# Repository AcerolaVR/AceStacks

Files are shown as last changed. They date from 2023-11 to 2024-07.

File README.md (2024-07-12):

# AceStacks
A compact, easy-to-assemble SlimeVR tracker design using all the standard recommended DIY tracker parts, and the commonly available 16340 battery.
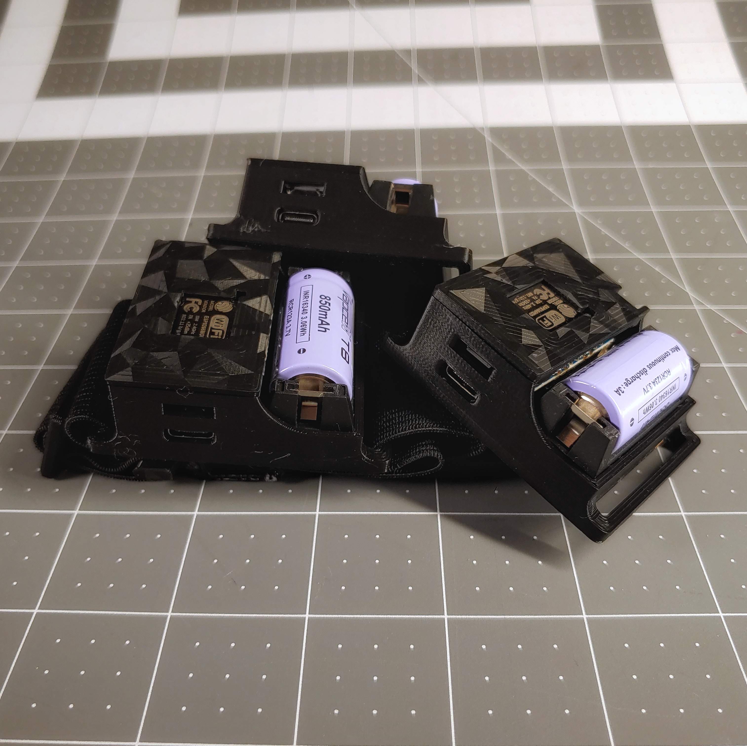
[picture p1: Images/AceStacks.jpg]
Screenshot of AceStacks V1 Trackers

# Overview
AceStacks is a compact, easy-to-assemble SlimeVR tracker design using all the standard recommended DIY tracker parts, and the commonly available 16340 battery. Here are some of the standout features of the AceStacks trackers.

- The use of the included pin sockets of the D1 Mini allows the MCU to be mounted over the charging board, resulting in a compact PCB footprint.
- The design of the board reduces the number of pin headers that need to be trimmed, one of the more annoying parts of DIY trackers with PCBs.
- 16340 cells are easier to obtain (in the United States, not sure about the rest of the world), relatively cheap, more durable compared to li-po pouch cells, and hot swappable if you need more battery life

This arrangement allows for a compact full body tracker with ~8 hours of battery life, battery sense, AUX tracker support, and a hot swappable battery.

# Parts
Refer to the Official SlimeVR Component Guide for more info https://docs.slimevr.dev/diy/components-guide.html

## Required Parts
- Microcontroller: Wemos D1 Mini // https://www.aliexpress.com/w/wholesale-D1-mini.html
- IMU: BMI160 // https://www.aliexpress.com/w/wholesale-BMI160.html
- Charging Board: TP4056 // https://www.aliexpress.us/item/2251832463465716.html
- Batteries: 16450 Li-ion Batteries // https://illumn.com/16340-vapcell-inr16340-t8-850mah-3a-high-discharge-button-top.html or https://liionwholesale.com/products/vapcell-t8-16340-rcr123a-3a-button-top-850mah-battery-genuine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
- CR123/16340 Battery Holders // https://www.aliexpress.com/w/wholesale-cr123-holder.html
- Power Switches: 12d19 Horizontal Switches // https://www.aliexpress.com/w/wholesale-12D19.html
- Straps: 1.5in or 38mm Straps // https://www.aliexpress.us/item/3256801722425879.html or 
https://www.aliexpress.us/item/3256802873749389.html

## Optional Parts
For Battery Percentage
- Resistors: 0805 SMD 180K Resistor // https://www.aliexpress.us/item/3256801607747550.html

For Charge Protection (a Jumper Pad is Provided if You Don't Use These"
- B5817W SOD-123 SMD Schottky Diodes // https://www.lcsc.com/product-detail/Schottky-Barrier-Diodes-SBD_JSMSEMI-B5817W_C917035.html

For Removable Extensions
- JST ZH1.5 4P Vertical Connector // https://www.aliexpress.us/item/3256802928739446.html
- JST ZH1.5 4P Wire // https://www.aliexpress.us/item/3256802896025388.html
Make sure you get the right pitch (ZH, p1.5) and pin count (4p)
The extension wires can be soldered directly to the same holes the JST connector is soldered to, but using a JST allows removal of the extension

# Setup
## AceStacks Specific Setup
Information related to the ports, battery, and layout for the AceStacks Tracker
https://www.youtube.com/watch?v=jQLkWUqJBMk

- There are two ports, the bottom USB C port is for charging the battery, though the battery can be removed and charged in an appropriate Lithium Ion battery charger.
- The top Micro-USB port is for data. You’ll use the data port during initial setup to configure the wi-fi and to debug the trackers if necessary.
- SlimeVR trackers are programmed with a set orientation. As programmed, AceStacks should be worn on the body such that the USB ports are facing the ceiling. This only matters for manual mounting.

### Data Port Quirks
The USB cable may not fully seat in the data port, preventing a proper data connection with the tracker. If you’re having trouble connecting, try the following
- Hold and firmly press the cable into the tracker to form a proper connection
- Use a USB cable with, or trim back the rubber sheath on a cable to allow you to insert the USB cable further into the port
- If neither of the above work, you may need to partially disassemble the tracker, remove the microcontroller, and connect directly to the usb port

### Safety, Charging and Battery Information
If replacing the battery, such as to place fresh ones in or if one accidentally fell out, make sure to place the battery polarity correctly.
- The battery has a flat negative pole, and a button top positive pole
- Follow the battery holder markings for + and -
- The negative pole should be closer to the side with the data and charging port, and the positive side should be on the opposite side

**Placing the battery in the wrong polarity and turning on the tracker will damage the tracker**

## Software Setup
Refer to the official SlimeVR documentation to set up the server and configure your trackers for use.

Quick setup guide for SlimeVR: https://docs.slimevr.dev/quick-setup.html
Detailed setup guide: https://docs.slimevr.dev/server/index.html

# Credits
- The SlimeVR Team, for an incredible open-source project and community

- Errorbox, who’s tracker design using a similar stacked layout inspired this one

- 

- Fns720, for their modified GoPro Quick Release Locking Clip https://www.printables.com/model/19390-lockable-gopro-quick-release-clip
https://www.thingiverse.com/thing:3375200

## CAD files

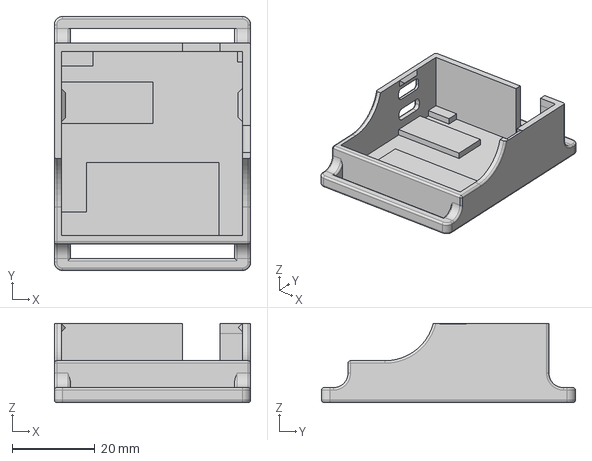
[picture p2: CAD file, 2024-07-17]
STEPs/AceStacksCase.step
47.4 x 61.4 x 19.1 mm

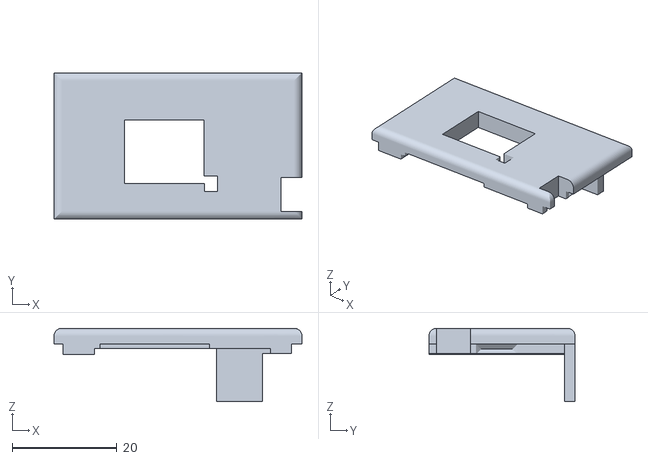
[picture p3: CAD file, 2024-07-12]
STLs/AceStacksLidSmoothAux.stl
47.4 x 28.0 x 14.0

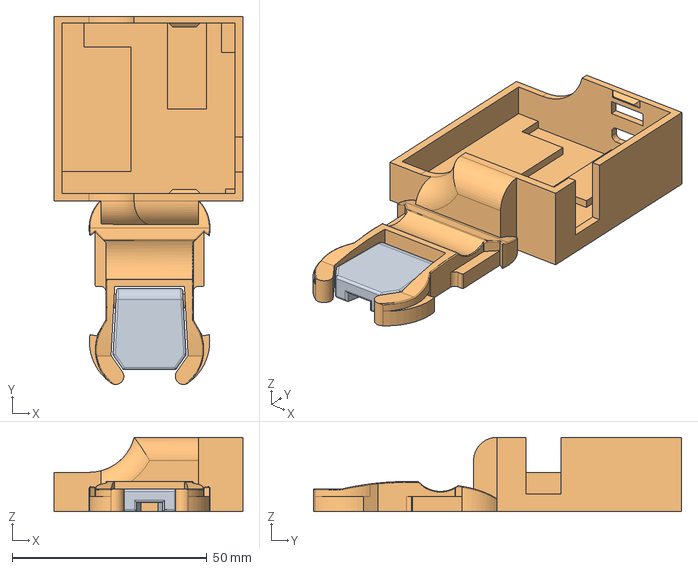
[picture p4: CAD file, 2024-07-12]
STEPs/AceStacksGoProCase.step
48.6 x 94.6 x 19.1 mm

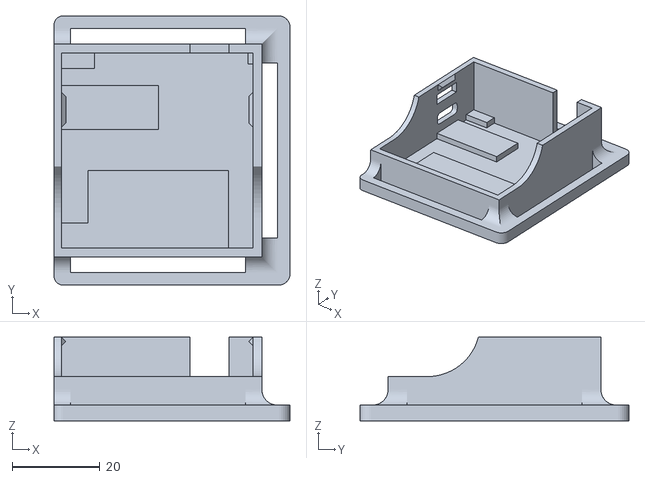
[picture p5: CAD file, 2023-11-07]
STLs/AceStacksCaseGarter.stl
53.8 x 61.4 x 19.1

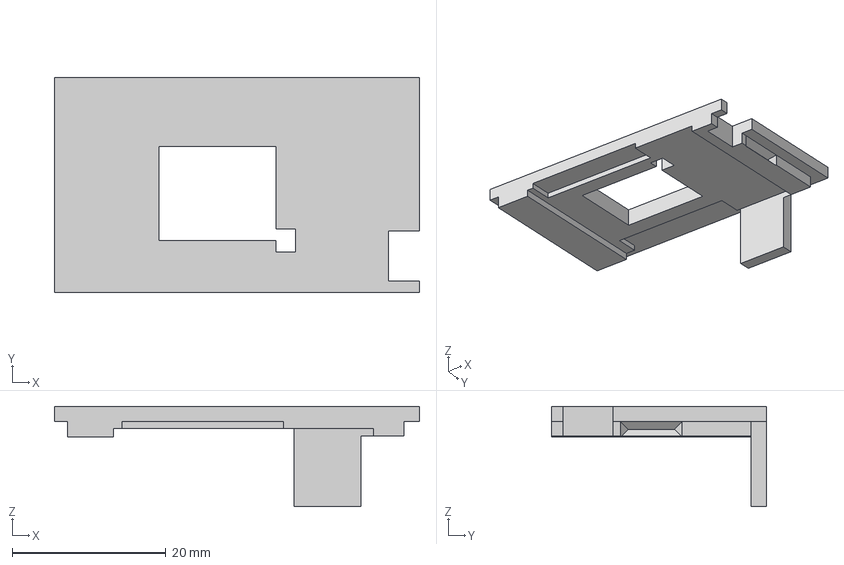
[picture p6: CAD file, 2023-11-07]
STEPs/AceStacksLidAUX.step
47.4 x 28.0 x 13.0 mm

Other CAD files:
STEPs/AceStacksLid.step
STEPs/CaseGarter.step
STEPs/AceStacksLidSmooth.step
STEPs/AceStacksCasev1.1.step
STLs/AceStacksCase.stl
STLs/AceStacksGoProCase.stl
STLs/AceStacksLidSmooth.stl

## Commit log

2023-11-07 added Gerber Files and image
2023-11-07 added STEP and STL files
    [AceStacksCase.step, AceStacksCase.stl, AceStacksCaseGarter.stl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]
2024-01-19 Add files via upload
    Recessed the usb port hole for the d1, sidestepping the loose connection issue that may happen
    [AceStacksCase.step]
2024-07-12 Acestacks v1 final update, w/ updated 3d files and project
    [AceStacksCase.step, AceStacksCase.stl, AceStacksCasev1.1.step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]
